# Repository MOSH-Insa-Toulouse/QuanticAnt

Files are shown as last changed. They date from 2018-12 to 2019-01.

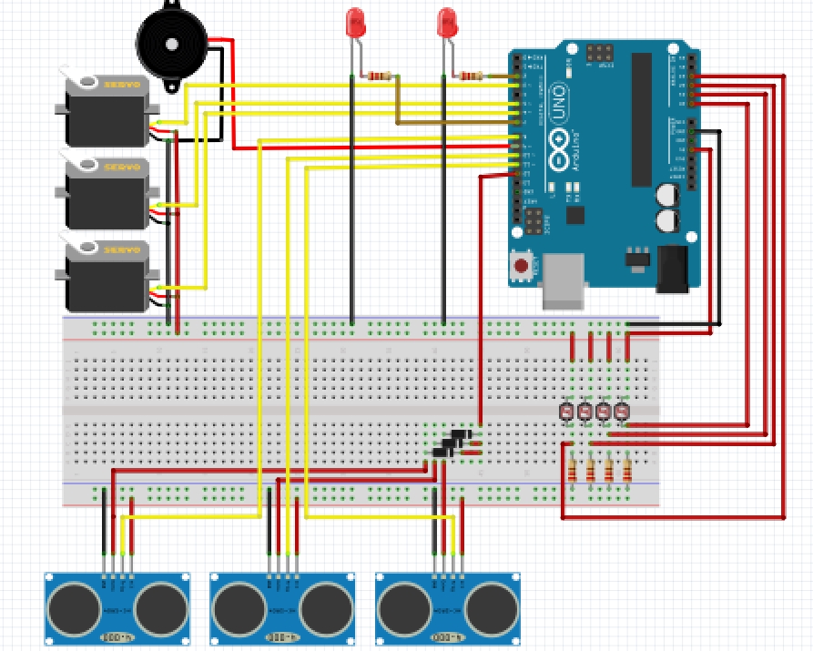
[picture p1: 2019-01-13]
Images et presentation/vueShematique.jpg

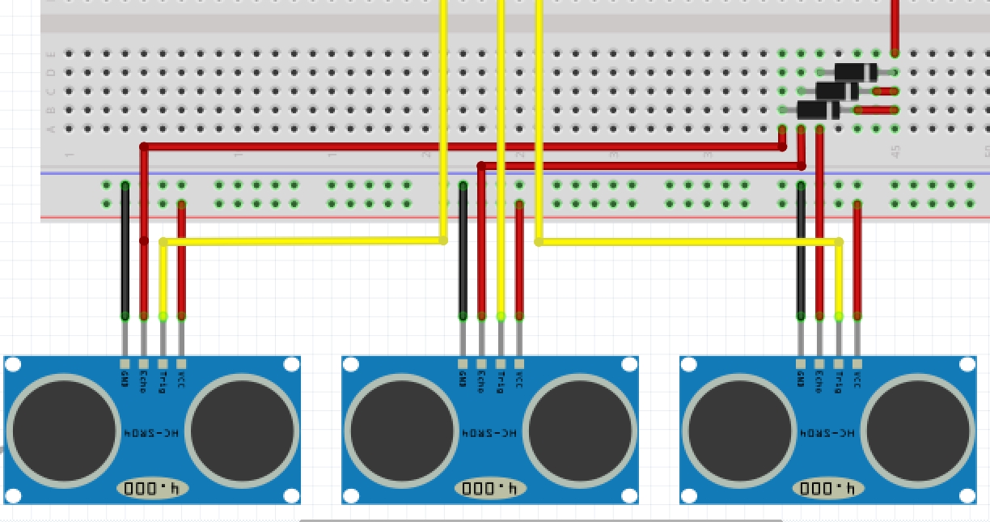
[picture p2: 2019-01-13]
Images et presentation/vueDetailUS.jpg

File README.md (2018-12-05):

# Projet_MOSH 

Auteurs : Quentin Martinez, Nicolas Baudeau, Soufian Yjjou

Caractéristiques de "QuanticAnt" :

Basé sur une arduino, QuanticAnt est un "robot" de petite taille équipé de 4 pattes lui permettant de se déplacer sur le sol.
Les solutions de détections lui permettent d'éviter les obstacles et d'évoluer de façon aléatoire dans une pièce.

QuanticAnt est repoussé par la lumière et emet un son aggaçant quand il se sent bien (peu de lumière ambiante).
Pour prendre le controle de cet insecte l'éclairer directement le force vers une direction donnée.

Mots clés : MARCHE ALEATOIRE, LUMIERE, SANS ROUES, DETECTION D'OBSTACLES

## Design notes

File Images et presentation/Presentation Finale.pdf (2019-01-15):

# Projet MOSH

## Réalisation d’un robot

## “intelligent” : QuanticAnt

BAUDEAU Nicolas - MARTINEZ Quentin - YJJOU Soufian

15/01/2019

# Sommaire

## - Présentation du projet

## - Développement Hardware

## - Développement Software

## - Conclusion

# Présentation du projet

# Objectifs

Idée de départ : Robot imitant le comportement d’un insecte qui a peur de la lumière

Fonctions principales de QuanticAnt :

➔ Éviter les obstacles proches
➔ Gestion de la luminosité (photosensible)
➔ Déplacement aléatoire sur pattes mécaniques
➔ S’immobilise et chante en cas de faible luminosité (mode veille)

# Résultat

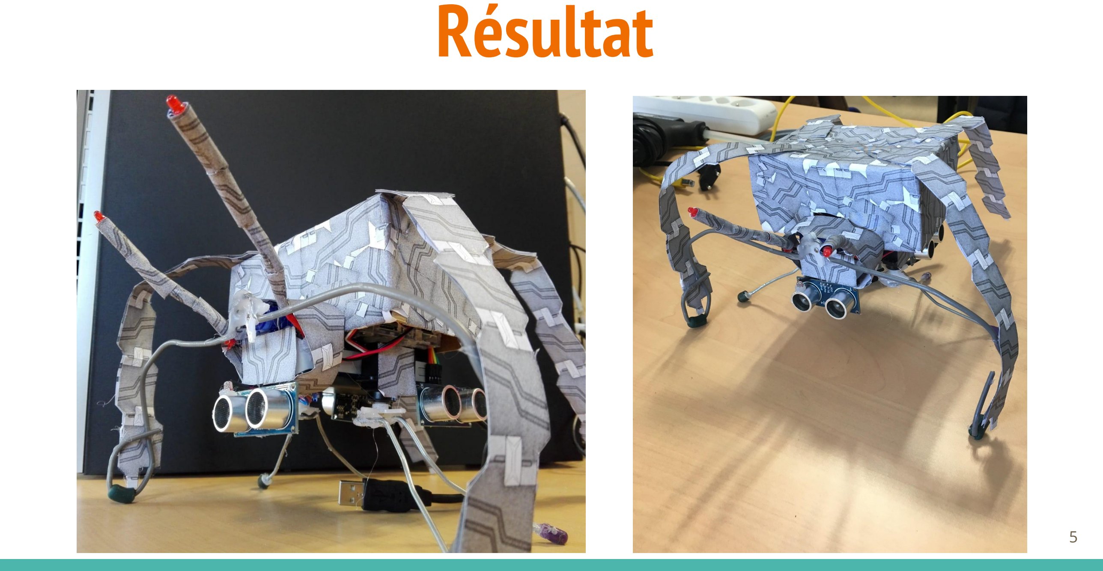
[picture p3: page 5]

# Hardware

# Vue globale de QuanticAnt

Moteurs latéraux | Déphasage pour
permettre le mouvement
Moteur central | Synchronisé pour
permettre le réarmement des pattes latérales
Module ultrason | Détection d’obstacles
Photorésistance | Détection de lumière
Buzzer | Génération du bruit
Led | Antennes clignotantes
Batterie | Alimentation Arduino UNO +
Alimentation moteur

# Composants et prix

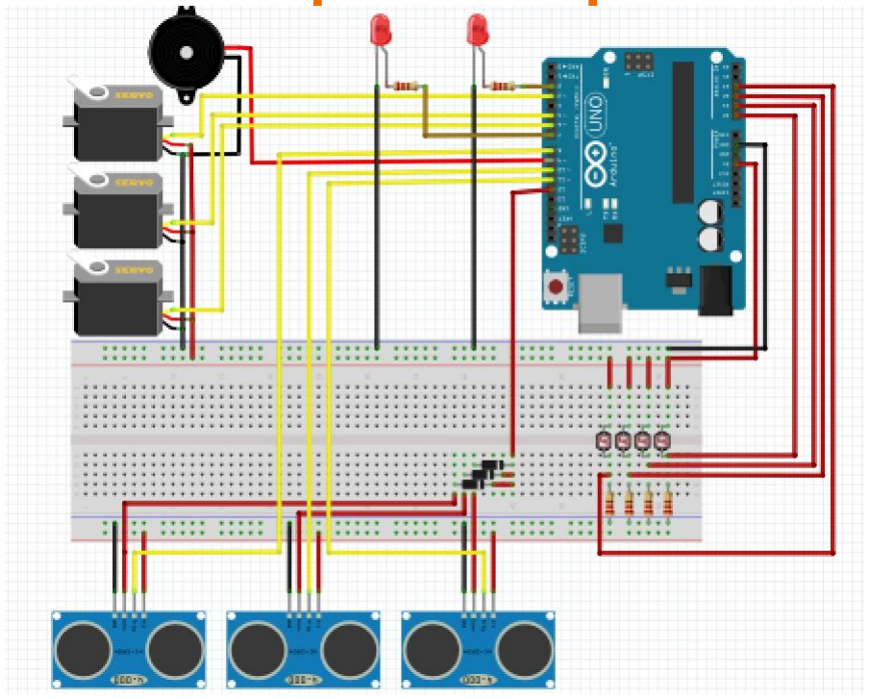
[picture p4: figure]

# Composants et prix

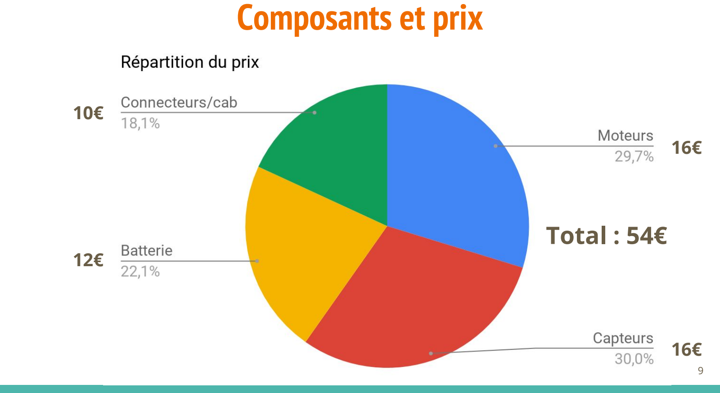
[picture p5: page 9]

## Total : 54€

10€

12€

16€

16€

# Utilisation des modules ultrason

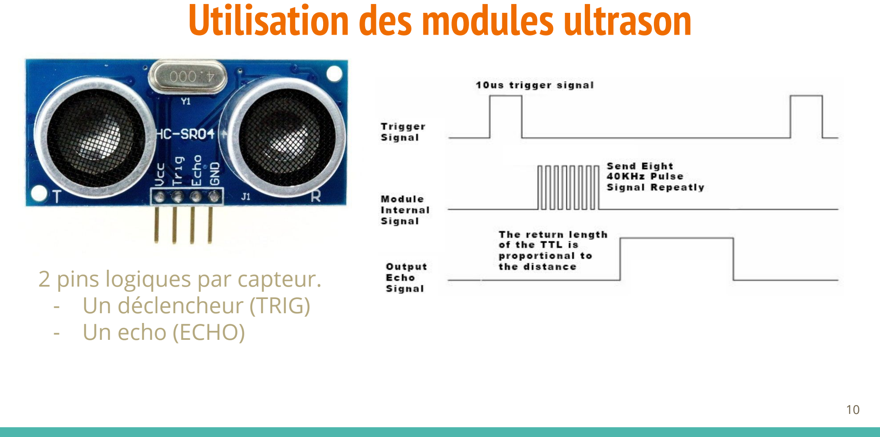
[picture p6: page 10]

2 pins logiques par capteur.
- Un déclencheur (TRIG)
- Un echo (ECHO)

# Utilisation des modules ultrason

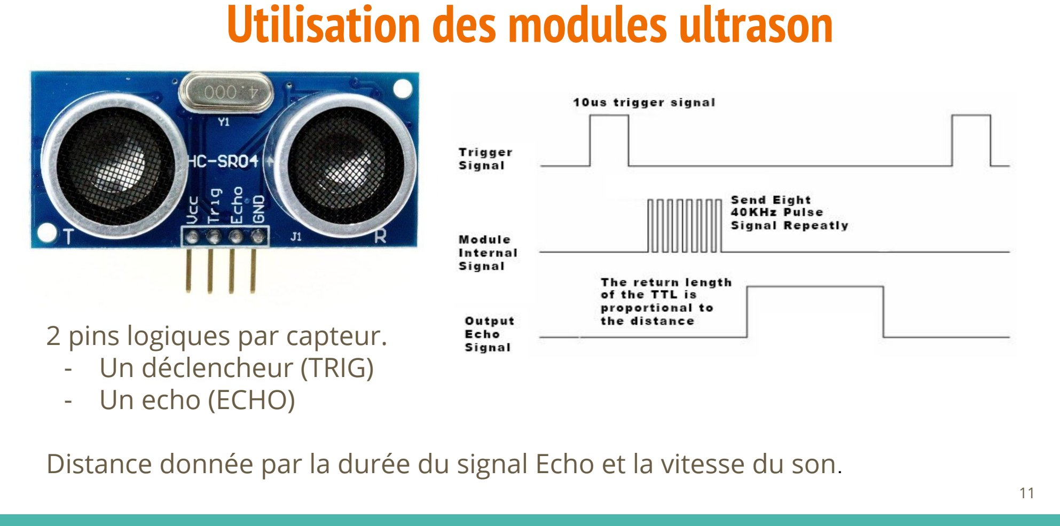
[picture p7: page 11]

2 pins logiques par capteur.
- Un déclencheur (TRIG)
- Un echo (ECHO)

Distance donnée par la durée du signal Echo et la vitesse du son.

# Astuce d’utilisation des modules ultrason

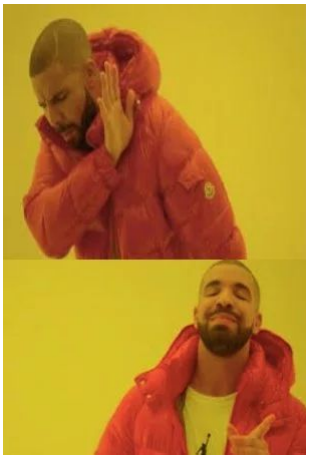
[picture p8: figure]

### 6 pins logiques sur l’arduino…

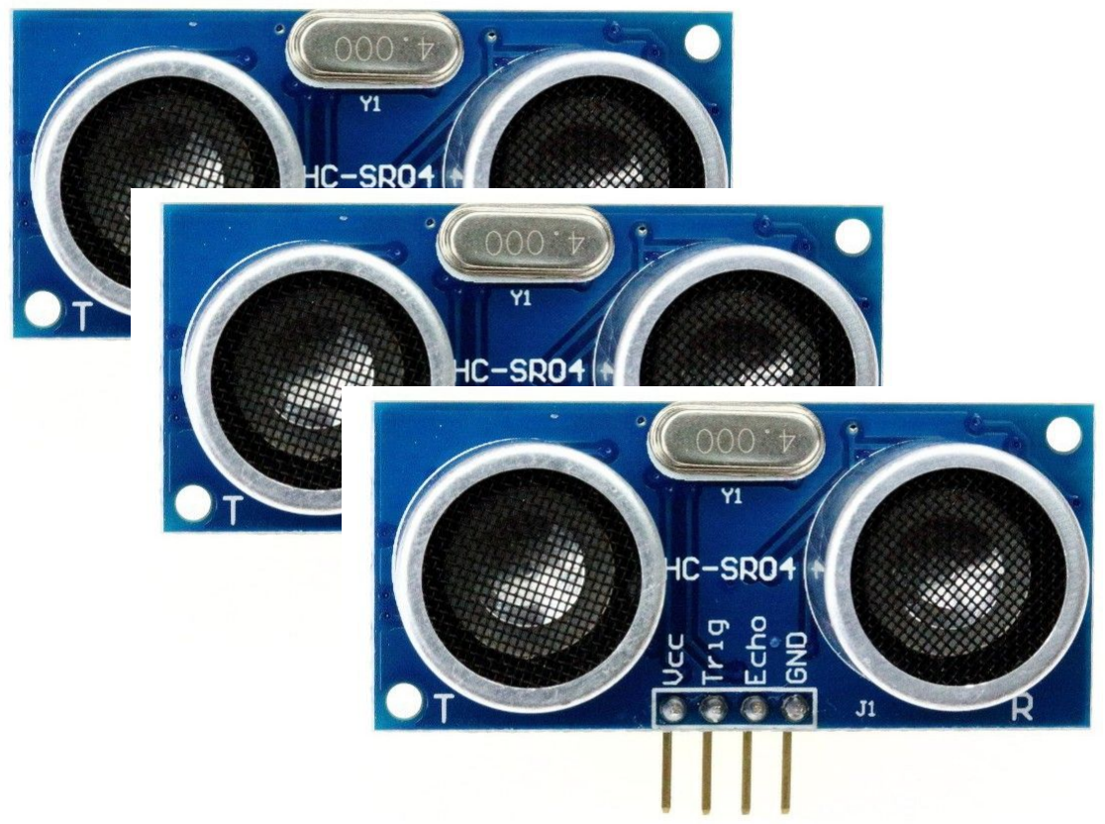
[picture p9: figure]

### 4 pins logiques sur l’arduino…

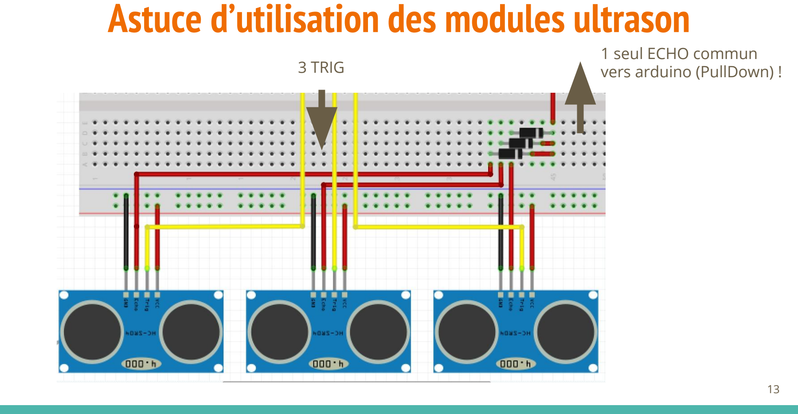
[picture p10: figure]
3 TRIG; 1 seul ECHO commun vers arduino (PullDown) !

# Astuce d’utilisation des modules ultrason

# La conception du PCB (Kicad)

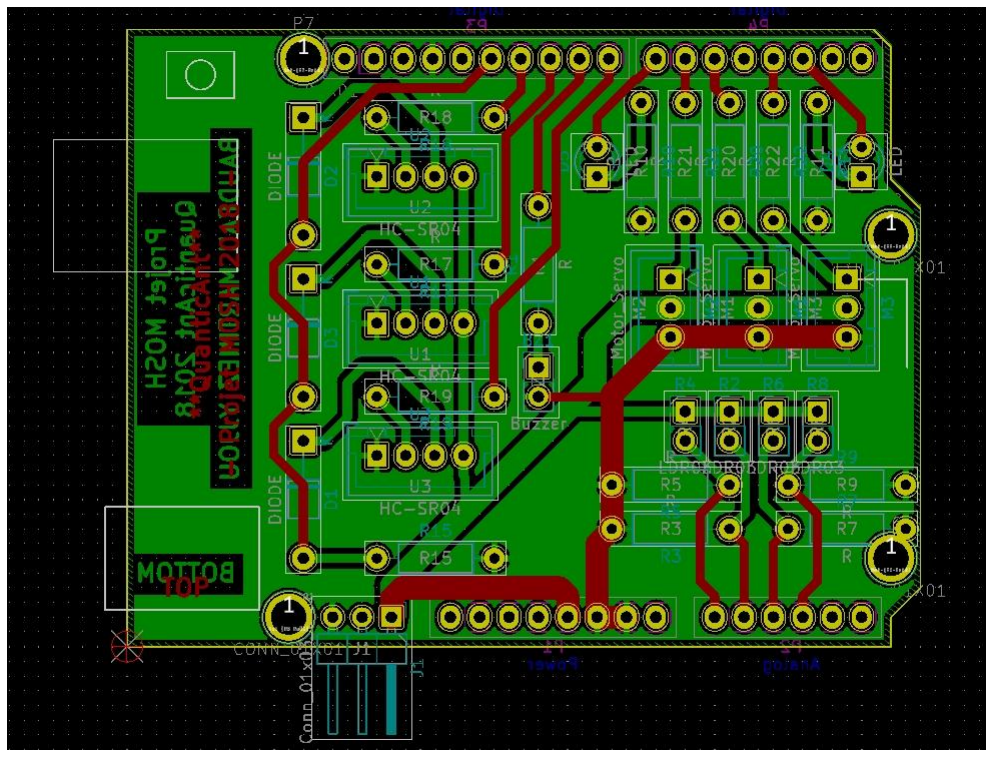
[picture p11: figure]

PCB double face pour :
- Connecter les actionneurs / capteurs
- Contenir les ponts diviseurs des capteurs
- Le système d’Echo commun

# La conception du PCB (Kicad)

PCB double face pour :
- Connecter les actionneurs / capteurs
- Contenir les ponts diviseurs des capteurs
- Le système d’Echo commun

Astuces :
- Indiquer sur les 2 faces “TOP” et “BOTTOM”
- Grossir les pistes des moteurs (puissance)
- Utiliser les pattes des composants comme via

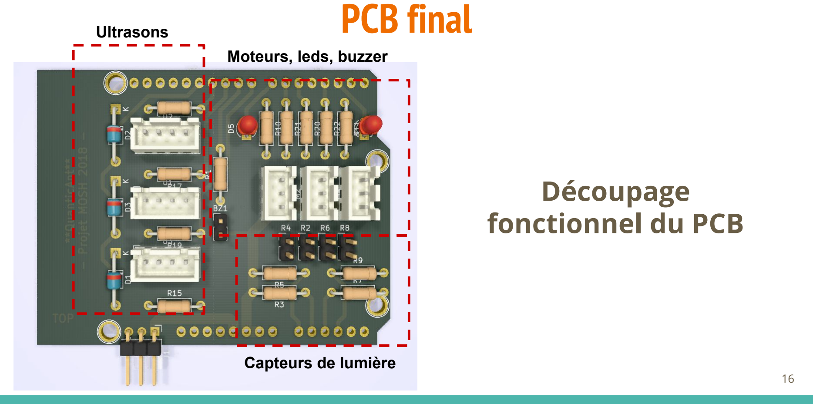
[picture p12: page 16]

Ultrasons | PCB final

Capteurs de lumière

Moteurs, leds, buzzer

## Découpage fonctionnel du PCB

# Software

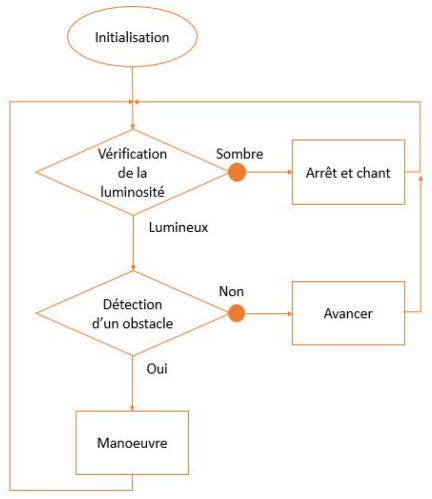
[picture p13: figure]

# Logique de bord

# Logigramme général du robot

# Détection d’un obstacle

➔ Retourne la distance en mm entre le capteur "Broche" et un obstacle à moins de 2m (dure 6ms environ)

➔ Signal = Temps (en ms) entre l’envoie de l'ultrason et ping de réception de l’écho

➔ Conversion du temps en distance 343 m/s soit 0.0343 mm/s = 1/29.1

float DistUS(int Broche)

{
float Dist = 0.0;

//Impulsion pour le capteur ultrason

digitalWrite(Broche, LOW); delayMicroseconds(5);
digitalWrite(Broche, HIGH); delayMicroseconds(10);
digitalWrite(Broche, LOW);

// Lecture du signal détecté par le capteur ultrason.

pinMode(ECHO, INPUT);
Dist = (pulseIn(ECHO, HIGH, 15000)/2) / 29.1;

if(Dist == 0)
return ( 200.0);
else
return (Dist);

# Détection de la luminosité

➔ Retourne la luminosité la plus forte parmi les 4 capteurs

➔ LUXF = Lumière capté devant le robot
➔ LUXR = Lumière capté à droite du robot
➔ LUXG = Lumière capté à gauche du robot
➔ LUXB = Lumière capté derrière le robot

int MaxLux()

{

int maxL = analogReadN(LUXF, 10);

if( analogReadN(LUXL, 10) > maxL) maxL = analogReadN(LUXL, 10);

if( analogReadN(LUXR, 10) > maxL) maxL = analogReadN(LUXR, 10);

if( analogReadN(LUXB, 10) > maxL) maxL = analogReadN(LUXB, 10);

return maxL;

}

# Fonction motrice

➔ On contrôle la (phase) des moteurs en degré (0-180°)

➔ La valeur Dir donne la direction ( 8 = avancer, 4 et 6 = tourner, 2 = reculer)

➔ A = moteur de droite
B = moteur de gauche
C = moteur central

➔ La phase A et B oscillent entre 60° et 130° (pas de 4°)

void Motrice(int vitesse, int dir)

{
if(posA<=59)
sensA =4;
if( posA >= 130)
sensA = -4;

if(posB<=59)
{
sensB =4;

//Contrôle de la phase C au moment où B est en butée

if(dir ==8 || dir == 6)
posC = 70;
else // Dans le cas de la marche avant ou rotation Droite on inverse le mouvement
posC = 110;

# Fonction motrice

➔ La direction désirée est obtenue en corrigeant la position des moteurs A et C en fonction de la position du moteur B

➔ La vitesse est déterminé par le temps d’attente entre deux mouvements

if( posB >= 130)
{
sensB = -4;

//Correction du déphasage avec A selon la direction if(dir ==8 || dir == 2)
posA = 59;
if(dir ==4 || dir == 6)
posA = 130;

//Correction du déphasage avec C selon la direction if(dir == 2 || dir == 4)
posC = 70;
else
posC = 110;
}

posA+=sensA;
posB+=sensB;
phaseA.write(posA);
phaseB.write(posB);
phaseC.write(posC);
delay(80/vitesse);
}

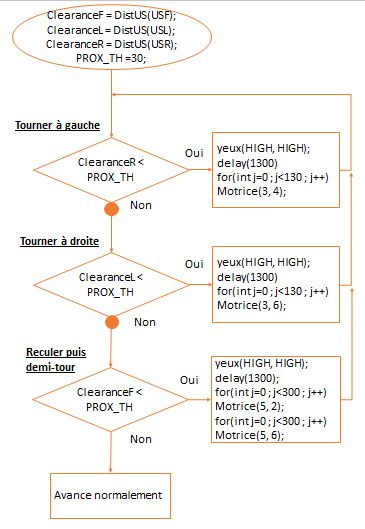
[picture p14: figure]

# Gestion des collisions

# Organigramme de déplacement du robot

# Conclusion

# Difficultés rencontrées

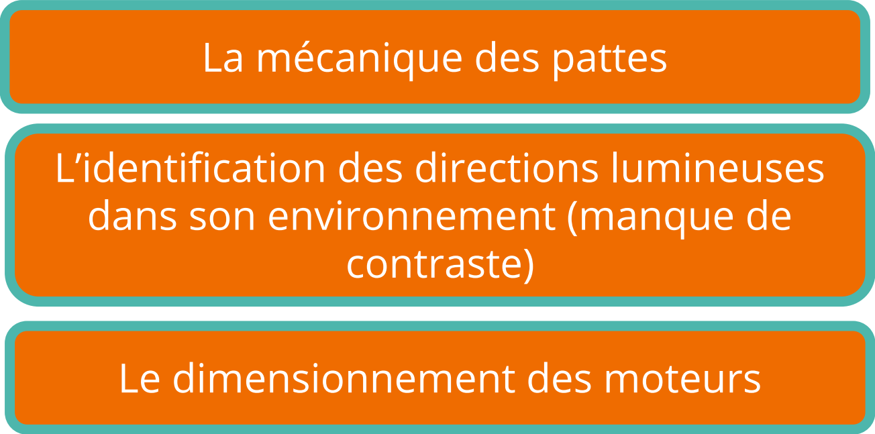
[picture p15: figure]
La mécanique des pattes; dans son environnement (manque de contraste); Le dimensionnement des moteurs

## L’identification des directions lumineuses

# Perspectives d’évolution

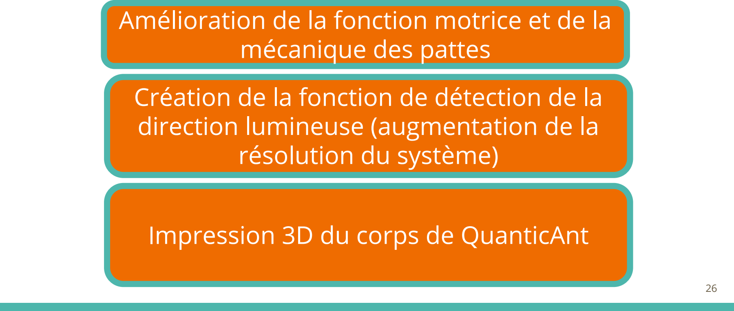
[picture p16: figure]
mécanique des pattes; direction lumineuse (augmentation de la résolution du système); Impression 3D du corps de QuanticAnt

## Amélioration de la fonction motrice et de la

## Création de la fonction de détection de la

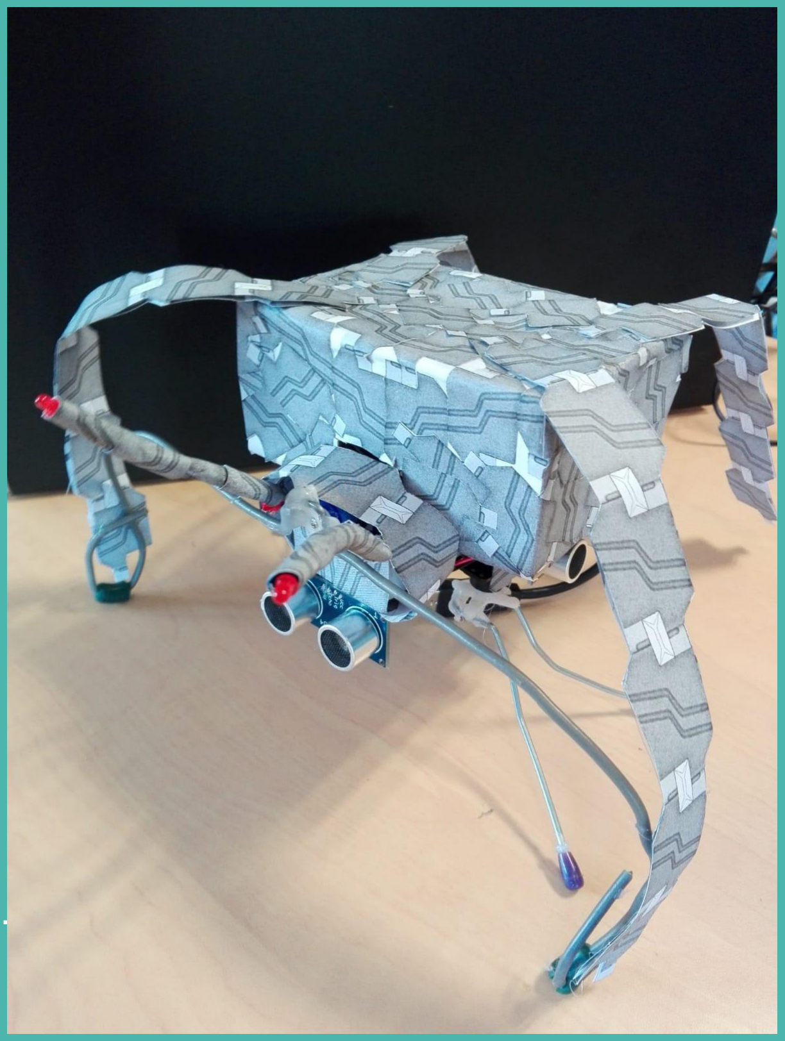
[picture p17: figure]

# Merci de votre attention Démonstration ?

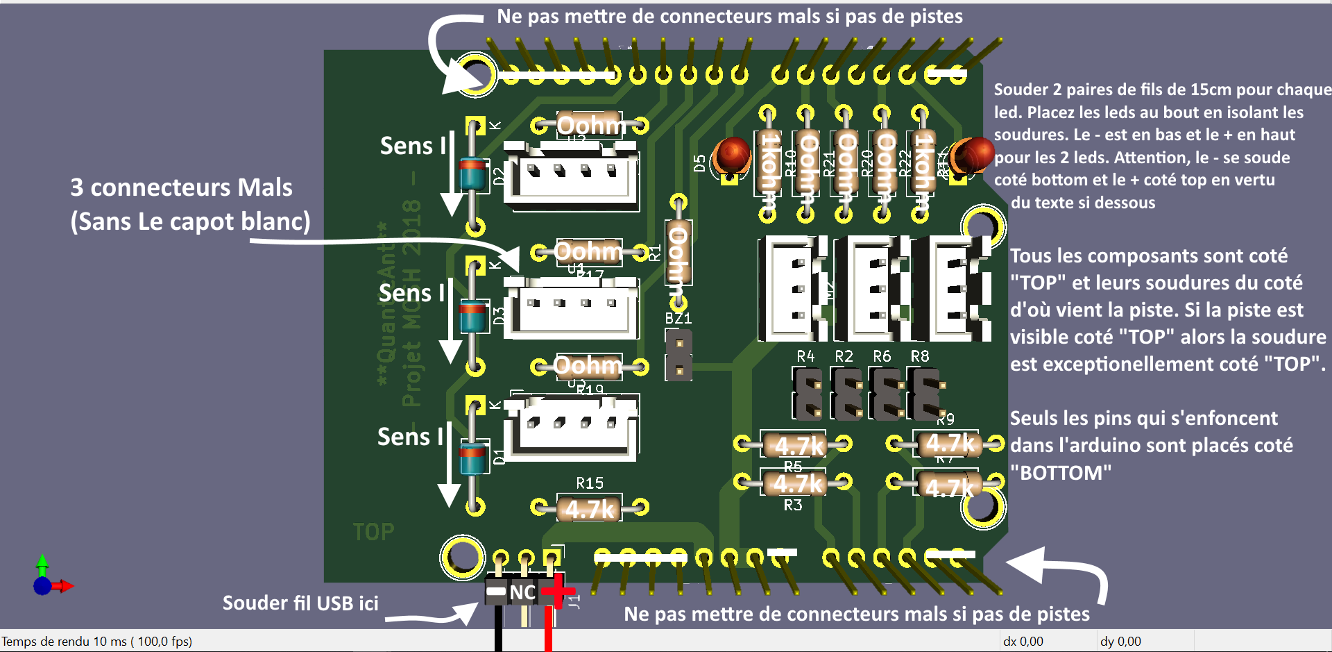
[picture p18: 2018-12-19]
Hardware/PCB/info.png

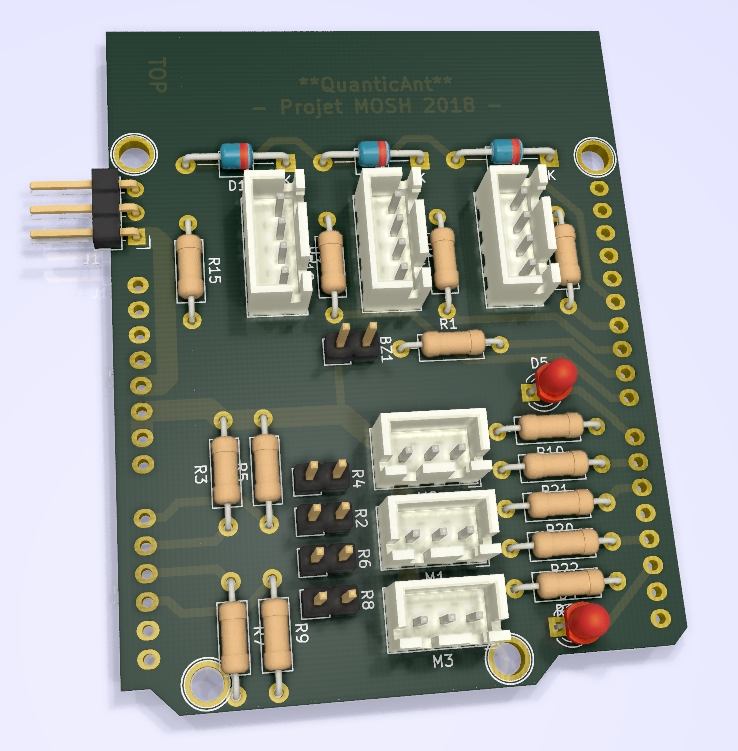
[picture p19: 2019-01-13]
Images et presentation/PCB_3D.jpg

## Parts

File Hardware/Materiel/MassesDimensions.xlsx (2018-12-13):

Projet QuanticAnt
Liste de composants
Designation | Quantité | Longeur(mm) | Largeur (mm) | Profondeur (mm) | masse (g)
Capteurs US | 3 | 45 | 20 | 17 | 7.8
LDR | 4 | 2 | 5 | 5 | 0.2
Arduino Uno + 3Moteurs + Bat + acrylic | 1 | 100 | 80 | 40 | 192
Structure metal Arriere | 1 | 250 | 90 | 50 | 14.7
Structure metal Laterale | 2 | 70 | 80 | 50 | 6.4
Sheild | 1 | 80 | 68 | 20 | 20 | (estimé)
Servo | 1 | 20 | 10 | 30 | 10.9
ON/OFF | 1 | 15 | 18 | 18 | 4.1
Corps 3D printed | 1 |  | 0
led rouge | 2 | 5 | 3 | 3 | 0.1
Buzzer | 1 | 5 | 22 | 22 | 2.3
1n4148 | 3 |  |  |  | 0.1

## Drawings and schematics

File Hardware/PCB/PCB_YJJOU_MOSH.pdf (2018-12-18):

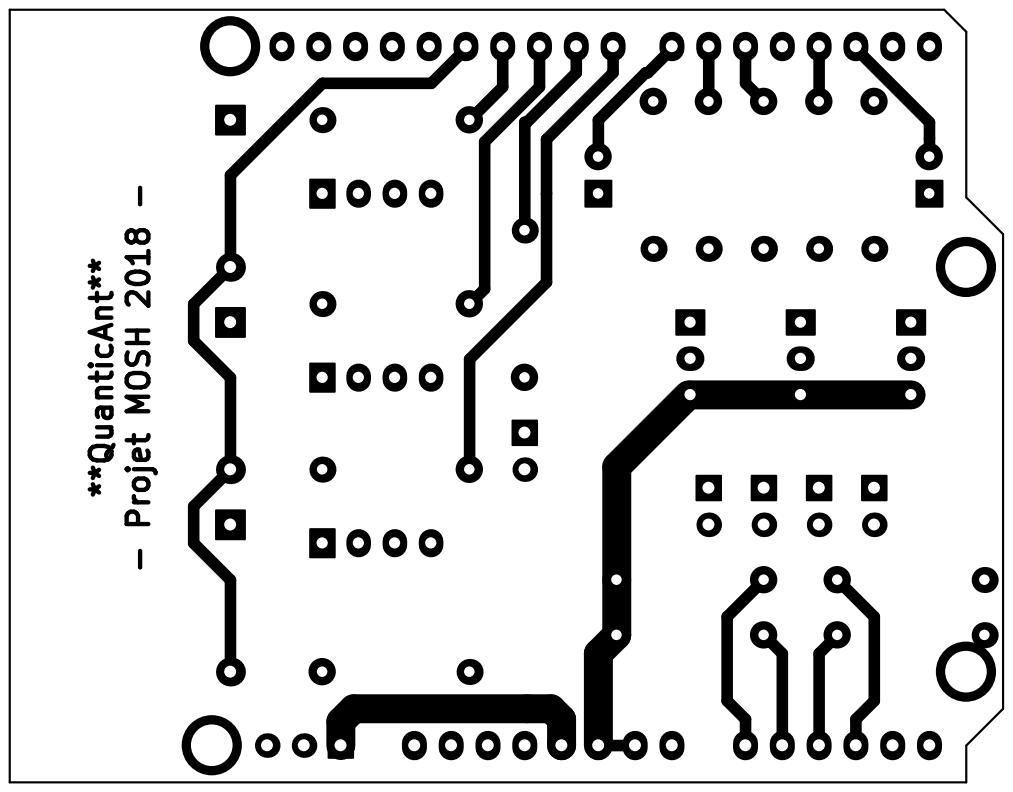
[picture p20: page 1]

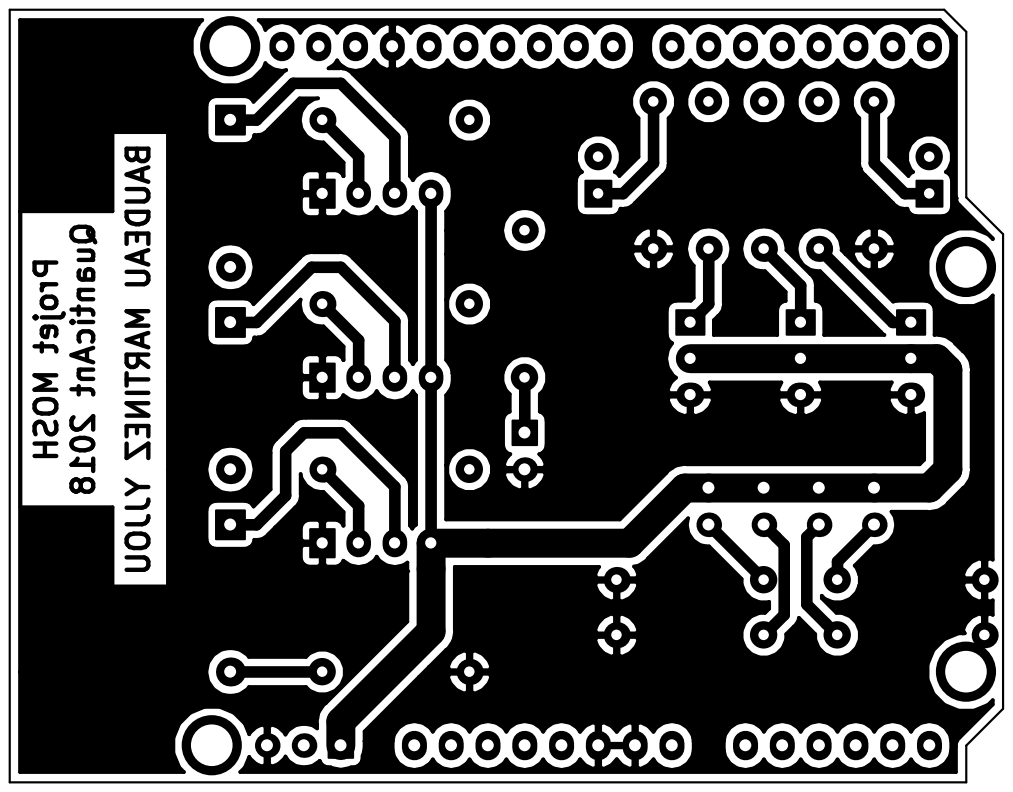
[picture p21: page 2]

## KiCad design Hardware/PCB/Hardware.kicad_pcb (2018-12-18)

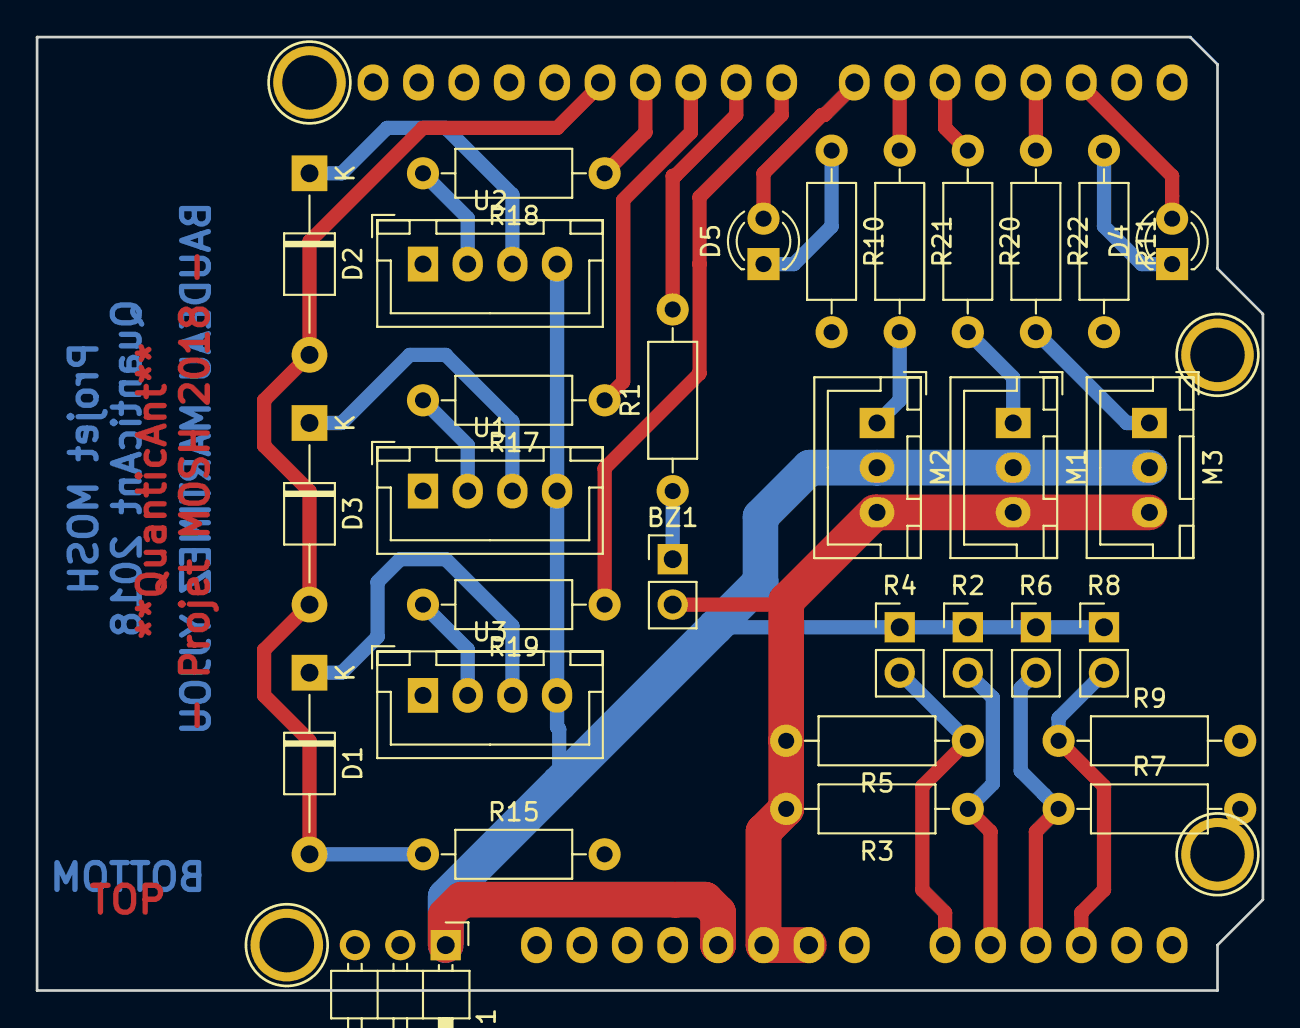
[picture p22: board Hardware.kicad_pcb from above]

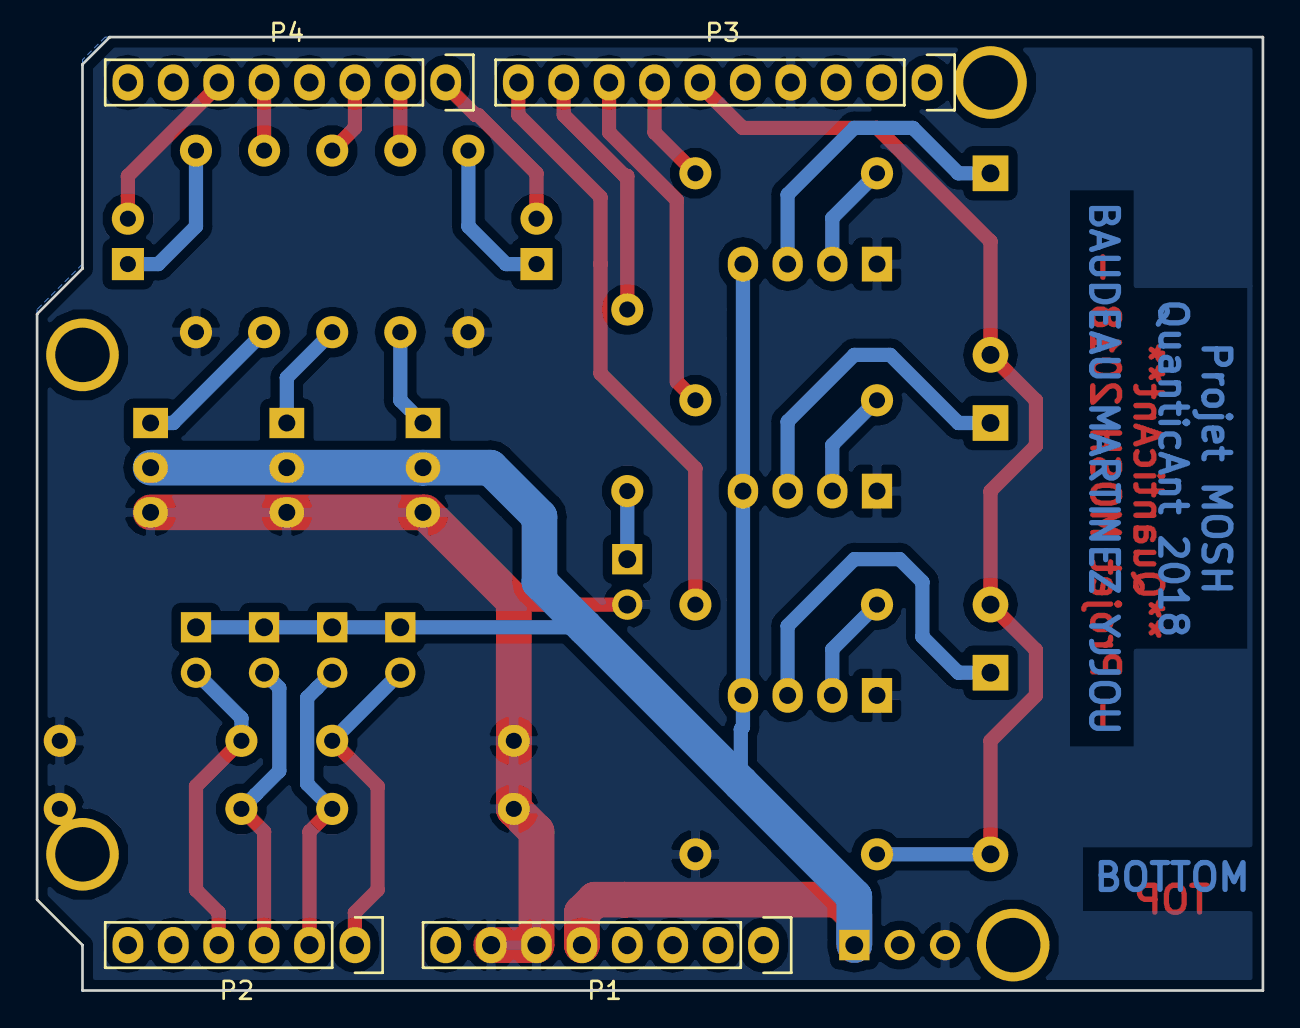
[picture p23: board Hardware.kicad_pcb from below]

Board: 2 copper layers, 68.6 x 53.3 mm, 39 parts (4 on the bottom side), 28 nets.

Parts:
BZ1: Buzzer; PinHeader_1x02_P2.54mm_Vertical
D1, D2, D3: DIODE; D_T-1_P10.16mm_Horizontal
D4, D5: LED; LED_D3.0mm
J1: Conn_01x03_Male; PinHeader_1x03_P2.54mm_Horizontal
M1, M2, M3: Motor_Servo; JST_XH_B03B-XH-A_1x03_P2.50mm_Vertical
P1: Power; Socket_Strip_Arduino_1x08
P2: Analog; Socket_Strip_Arduino_1x06
P3: Digital; Socket_Strip_Arduino_1x10
P4: Digital; Socket_Strip_Arduino_1x08
P5, P6, P7, P8: CONN_01X01; Arduino_1pin
R1, R3, R5, R7, R9, R10, R11, R15, R17, R18, R19, R20, R21, R22: R; R_Axial_DIN0207_L6.3mm_D2.5mm_P10.16mm_Horizontal
R2, R4, R6, R8: LDR03; PinHeader_1x02_P2.54mm_Vertical
U1, U2, U3: HC-SR04; JST_XH_B04B-XH-A_1x04_P2.50mm_Vertical

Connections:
+5V: J1.1, M1.2, M2.2, M3.2, P1.5, R2.1, R4.1, R6.1, R8.1, U1.4, U2.4, U3.4
/2: D4.2, P4.6
/3(**): P4.5, R22.1
/5(**): P4.3, R20.1
/6(**): P4.2, R21.1
/7: D5.2, P4.1
/8: P3.10, R19.1
/9(**): P3.9, R1.2
/10(**/SS): P3.8, R17.1
/11(**/MOSI): P3.7, R18.1
/12(MISO): D1.2, D2.2, D3.2, P3.6, R15.1
/A0: P2.1, R4.2, R5.1
/A1: P2.2, R2.2, R3.1
/A2: P2.3, R6.2, R7.1
/A3: P2.4, R8.2, R9.1
GND: BZ1.2, J1.3, M1.3, M2.3, M3.3, P1.6, P1.7, P3.4, R3.2, R5.2, R7.2, R9.2, R10.2, R11.2, R15.2, U1.1, U2.1, U3.1
unnamed: BZ1.1, R1.1
unnamed: D1.1, U3.3
unnamed: D2.1, U2.3
unnamed: D3.1, U1.3
unnamed: D4.1, R11.1
unnamed: D5.1, R10.1
unnamed: M1.1, R20.2
unnamed: M2.1, R21.2
unnamed: M3.1, R22.2
unnamed: R17.2, U1.2
unnamed: R18.2, U2.2
unnamed: R19.2, U3.2

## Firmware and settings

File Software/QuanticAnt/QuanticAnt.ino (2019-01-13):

/***********************************************************************
* 
*.______   .______        ______          __   _______ .___________.   .___  ___.   ______        _______. __    __  
*|   _  \  |   _  \      /  __  \        |  | |   ____||           |   |   \/   |  /  __  \      /       ||  |  |  | 
*|  |_)  | |  |_)  |    |  |  |  |       |  | |  |__   `---|  |----`   |  \  /  | |  |  |  |    |   (----`|  |__|  | 
*|   ___/  |      /     |  |  |  | .--.  |  | |   __|      |  |        |  |\/|  | |  |  |  |     \   \    |   __   | 
*|  |      |  |\  \----.|  `--'  | |  `--'  | |  |____     |  |        |  |  |  | |  `--'  | .----)   |   |  |  |  | 
*| _|      | _| `._____| \______/   \______/  |_______|    |__|        |__|  |__|  \______/  |_______/    |__|  |__| 
*                                                                                                                    
* ___     ___    __    ___         ___     ___    __    ___                                                          
*|__ \   / _ \  /_ |  / _ \       |__ \   / _ \  /_ |  / _ \                                                         
*   ) | | | | |  | | | (_) |  ______ ) | | | | |  | | | (_) |                                                        
*  / /  | | | |  | |  > _ <  |______/ /  | | | |  | |  \__, |                                                        
* / /_  | |_| |  | | | (_) |       / /_  | |_| |  | |    / /                                                         
*|____|  \___/   |_|  \___/       |____|  \___/   |_|   /_/                                                          
*                                                                                                                    
*  ______      __    __       ___      .__   __. .___________. __    ______         ___      .__   __. .___________. 
* /  __  \    |  |  |  |     /   \     |  \ |  | |           ||  |  /      |       /   \     |  \ |  | |           | 
*|  |  |  |   |  |  |  |    /  ^  \    |   \|  | `---|  |----`|  | |  ,----'      /  ^  \    |   \|  | `---|  |----` 
*|  |  |  |   |  |  |  |   /  /_\  \   |  . `  |     |  |     |  | |  |          /  /_\  \   |  . `  |     |  |      
*|  `--'  '--.|  `--'  |  /  _____  \  |  |\   |     |  |     |  | |  `----.    /  _____  \  |  |\   |     |  |      
* \_____\_____\\______/  /__/     \__\ |__| \__|     |__|     |__|  \______|   /__/     \__\ |__| \__|     |__|      
*                                                                                                                    
* de l'équipe Nicolas, Quentin et Soufian
*  
* Le projet vise à réaliser un robot imitant le comportement d'un insecte.
* -Déplacements aléatoires sur pattes
* -Photosensible
* -Evitement d'obstacles proches
* -s'immobilise et "Chante" lorsque la luminosité est faible
* 
* 
* 
***********************************************************************/

#include <Servo.h> // Voir l'exemple "SERVO" dans le menu arduino

#define USL 11 //Ultrason Left
#define USF 8//Ultrason Front
#define USR 10//Ultrason Right
#define ECHO 12//Retour ultrason
#define BUZZ 9//Buzzer pin (doit etre PWM)
#define LUXL A0//Lumiere Front (doit etre analog)
#define LUXB A1//Lumiere Back (doit etre analog)
#define LUXR A2//Lumiere Left (doit etre analog)
#define LUXF A3//Lumiere Right (doit etre analog)
#define LEDR 2 // led droite rouge
#define LEDL 7 // led gauche rouge

#define PROX_TH 30 // distance en cm a partir de laquelle le robot veut changer de direction
#define NIGHTLEV 400 // Niveau de lumiere correspondant a la nuit (plus grande la valeur, plus facilement le robot passe en mode nuit)
//Variables globales
int C=0; //compteur de loop avec overflow
int quantic=0; // Valeur aleatoire entre 0 et 100 qui change a chaque boucle
int ClearanceF = 100; //distances ultrason mesurees front (defaut 1m)
int ClearanceR = 100;
int ClearanceL = 100;

//----Variables Motrices
//Sens de rotations et positions initiales
int sensA =1;
int sensB =-1;
int sensC =1;
int posA = 59;
int posB = 139;
int posC = 65;
Servo phaseA;  // Moteur droite pin 3
Servo phaseB;  // Moteur gauche pin 5
Servo phaseC;  // Moteur equilibrage pin 6








//Retourne la moyenne de N mesures (moins de bruit) Attention, ne pas utiliser sur un pont diviseur fragile. (>10kohm)
long analogReadN(int pin, int N)
{
  long moy = 0;
  for(int i=0; i<N ; i++)
    moy += analogRead(pin);
    
  return(moy/N);
}



// Fonction qui genere un bruit une fois invoquee. Inspiree de l'exemple "tone"
// Fonction bloquante, attention ! (le temps du bruit)
void bruit() {
    
    int melody[] =        {208, 494, 415, 494, 415}; //tons du buzzer
    int noteDurations[] = {96, 96, 96, 96, 96}; // Durees des tons
  
    for (int thisNote = 0; thisNote < 5; thisNote++)
    {
      int noteDuration = 3000 / noteDurations[thisNote];
      int pauseBetweenNotes = noteDuration * 1.30;
      tone(BUZZ, melody[thisNote], noteDuration);
      delay(pauseBetweenNotes);
      // stop the tone playing:
      noTone(BUZZ);
    }
}


//Fonction qui retourne la distance en mm entre le capteur "Broche" et un obstacle à moins de 2m.
//Bloque le code pendant 6ms max
float DistUS(int Broche) {
  float Dist = 0.0;
  //Impulsion pour le capteur US
  digitalWrite(Broche, LOW);
  delayMicroseconds(5);
  digitalWrite(Broche, HIGH);
  delayMicroseconds(10);
  digitalWrite(Broche, LOW);
 
  // Recupere le signal echo des capteurs
  // La duree est en microseconds
  pinMode(ECHO, INPUT);
  Dist = (pulseIn(ECHO, HIGH, 15000)/2) / 29.1;
  // conversion du temps en distance en divisant par 29.1
  if(Dist == 0)
   return ( 200.0);
  else
   return (Dist);   

}


// Retourne La direction sombre
int DirLowLux() {
  //Front, Right, Back, Left 0° -> 360° sens horaire
  int LumF =  analogReadN(LUXF, 10);
  int LumL =  analogReadN(LUXL, 10);
  int LumR =  analogReadN(LUXR, 10);
  int LumB =  analogReadN(LUXB, 10);

  if(LumF > LumR && LumF > LumL && LumF > LumB)
   return(2); // Derriere
  if(LumR > LumF && LumR > LumL && LumR > LumB)
   return(4); // gauche
 if(LumB > LumR && LumB > LumL && LumB > LumF)
   return(8); // Devant
 if(LumL > LumR && LumL > LumF && LumL > LumB)
   return(6); // Droite
}

//Retourne la luminosite la plus forte (sonde les 4 capteurs).
int MaxLux() {
  int maxL = analogReadN(LUXF, 10);
  if( analogReadN(LUXL, 10) > maxL)
     maxL = analogReadN(LUXL, 10);
  if( analogReadN(LUXR, 10) > maxL)
     maxL = analogReadN(LUXR, 10);
  if( analogReadN(LUXB, 10) > maxL)
     maxL = analogReadN(LUXB, 10);
  return maxL;
}


//Controle des yeux rouge du robot
void yeux(int droite, int gauche)
{
  digitalWrite(LEDR, droite);
  digitalWrite(LEDL, gauche);
}




// Deplace QuanticAnt a la vitesse speed. La valeur Dir donne la direction selon le pave numerique
//789 : 8 = avancer
//456 : 4 et 6 = tourner
//123 : 2 = reculer
void Motrice(int vitesse, int dir)
{

  //La phase A oscille entre 60 et 130
  if(posA<=59)
      sensA =4;
  if( posA >= 130)
      sensA = -4;

  // La phase B oscille entre 60 et 130
  if(posB<=59)
  {
      sensB =4;
      //Controle de la phase C au moment ou B est en butee
      if(dir ==8 || dir == 4)
        posC = 70;
      else // Dans le cas de la marche avant ou rotation Droite on inverse le mouvement
        posC = 110;
  }
    if( posB >= 130)
    {
      sensB = -4;

      //Correction du dephasage avec A selon la direction
      if(dir ==8 || dir == 2)
        posA = 59;
      if(dir ==4 || dir == 6)
        posA = 130;

      //Correction du dephasage avec C selon la direction  
      if(dir == 2 || dir == 6)
        posC = 70;
      else
        posC = 110;


    }
    
    posA+=sensA;
    posB+=sensB;
    phaseA.write(posA);           
    phaseB.write(posB);         
    phaseC.write(posC);        
    delay(80/vitesse);  
}





// Execution unique
void setup() {
  
  //Initialisation des capteurs US
  pinMode(LUXF, INPUT);
  pinMode(LUXB, INPUT);
  pinMode(LUXR, INPUT);
  pinMode(LUXL, INPUT);
  pinMode(USL, OUTPUT);
  pinMode(USF, OUTPUT);
  pinMode(USR, OUTPUT);
  pinMode(ECHO, OUTPUT);
  digitalWrite(USL, LOW);
  digitalWrite(USF, LOW);
  digitalWrite(USR, LOW);
  

  randomSeed(analogRead(A4)); // Recuperation des parasites pour generer le random
  
  //Preparation des moteurs
  phaseA.attach(3);
  phaseB.attach(5); 
  phaseC.attach(6);
  
  phaseA.write(posA);              
  phaseB.write(posB);        
  phaseC.write(posC);   

  
  Serial.begin(9600);


  //Le robot dit bonjour
  for(int j=0; j<5 ;j++)
  {
    bruit();
    yeux(HIGH, LOW);
    delay(50);
    yeux(LOW, HIGH);
    delay(50);
  }
  yeux(LOW, LOW);
}


/*Logique de bord :
1) Verifier la luminosité. Sombre => arret et chant
2) sinon verifier la position des obstacles => manoeuvre
3) sinon aller vers l'avant

Evolution possible : Utiliser les 4 capteurs de luminosite pour diriger le robot vers le noir.
Les capteurs sont presents mais pas utilises dans le code actuel. La fonction qui determine la direction sombre
est deja codee.
*/


void loop() {


  
  quantic = random(0, 100); // Nombre aleatoire de ce cycle

  //Recuperation des distances aux objets (prend du temps !!)
  ClearanceF = DistUS(USF);
  ClearanceL = DistUS(USL);
  ClearanceR = DistUS(USR);

  Serial.println("Avant "+String(ClearanceF));
  Serial.println("Gauche "+String(ClearanceL));
  Serial.println("Droite "+String(ClearanceR));
  Serial.println("--------");

  //Comportement dans le noir
  if(MaxLux() < NIGHTLEV)
  {
    //Comportement aleatoire des yeux
    if(quantic < 10)
      yeux(LOW, LOW);
    if(quantic >= 10 && quantic < 40)
      yeux(LOW, HIGH);
    if(quantic >= 40 && quantic < 80)
      yeux(HIGH, LOW);
    if(quantic >= 80)
      yeux(HIGH, HIGH);
      
    phaseC.write(90); // relaxe le moteur avant 
    delay(100);
    if(C%7 == 0)
      bruit(); //Blocant quelques diziemes de secondes
      
  }
  else // Il fait jour, on se deplace
  {
    yeux(LOW, LOW);
 
    //Gestion des collisions.
    if((ClearanceR < PROX_TH)) // Tourner vers gauche
    {
       yeux(HIGH, HIGH);
       delay(1300); // Le robot fait le mort
       for(int j=0 ; j<130 ; j++) 
        Motrice(3, 4);
    }
    else if( ClearanceL < PROX_TH)// Tourner vers droite
    {
       yeux(HIGH, HIGH);
       delay(1300); // Le robot fait le mort
       for(int j=0 ; j<130 ; j++) 
        Motrice(3, 6);
    }
    else if(ClearanceF < PROX_TH)// Reculer puis demi-tour
    {
     yeux(HIGH, HIGH);
     delay(1300); // Le robot fait le mort
    for(int j=0 ; j<300 ; j++) 
      Motrice(5, 2);
    for(int j=0 ; j<300 ; j++) 
      Motrice(5, 4);

    }
    if(ClearanceL>PROX_TH && ClearanceR>PROX_TH && ClearanceF>PROX_TH) // Aucun objet ne gene. On execute la marche habituelle du robot
    {

      //Fonction de marche aleatoire 1% dns un sens, 3% dans l'autre, 96% tout droit 
//    if(quantic < 2) // Parfois l'insecte tourne sans raison dans un sens
//    {
//     for(int j=0 ; j<30 ; j++) 
//        Motrice(3, 4);
//    }
//    if(quantic >= 2 && quantic < 5) // ou dans l'autre !
//    {
//     for(int j=0 ; j<30 ; j++) 
//        Motrice(3, 6);
//    }
//    if(quantic >= 5) // Le reste du temps il avance
//    {
//    for(int j=0 ; j<30 ; j++)   
//      Motrice(3, 8);
//    }
//    Serial.println(quantic);
//    Motrice(8, DirLowLux()); // Suivi de direction sombre desactive. (instable, besoin de lissage).
//    Serial.println("LowLUX "+String(DirLowLux()));
      for(int j=0 ; j<40 ; j++)   
      Motrice(3, 8);

    
   }

  }
  

  C++; // Compteur de boucle
}

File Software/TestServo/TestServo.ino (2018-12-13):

/* Sweep
 by BARRAGAN <http://barraganstudio.com>
 This example code is in the public domain.

 modified 8 Nov 2013
 by Scott Fitzgerald
 http://www.arduino.cc/en/Tutorial/Sweep
*/

#include <Servo.h>

//Sens de rotations et positions initiales
int sensA =1;
int sensB =-1;
int sensC =1;
int posA = 59;
int posB = 139;
int posC = 65;
Servo phaseA;  // Moteur droite
Servo phaseB;  // Moteur gauche
Servo phaseC;  // Moteur equilibrage


void setup() {
  phaseA.attach(9);  // attaches the servo on pin 9 to the servo object
  phaseB.attach(10);  // attaches the servo on pin 9 to the servo object
  phaseC.attach(11);  // attaches the servo on pin 9 to the servo object
  Serial.begin(9600);
     phaseA.write(posA);              // tell servo to go to position in variable 'pos'
    phaseB.write(posB);              // tell servo to go to position in variable 'pos'
    phaseC.write(posC);   
  delay(500);

  pinMode(3, INPUT);
  
}

// vitesse de 1 a 5
// dir valeurs acceptees 2, 4, 6, 8.(pave num)
void motrice(int vitesse, int dir)
{
  if(posA<=59)
      sensA =4;
  if( posA >= 130)
      sensA = -4;

    if(posB<=59)
    {
      sensB =4;
      if(dir ==2 || dir == 6)
        posC = 70;
      else
        posC = 110;
    }
    if( posB >= 130)
    {
      if(dir ==2 || dir == 8)
        posA = 59;
     if(dir ==4 || dir == 8)
        posA = 130;
      sensB = -4;
      if(dir == 8 || dir == 4)
        posC = 70;
      else
        posC = 110;
    }
    
    posA+=sensA;
    posB+=sensB; 
    phaseA.write(posA);              // tell servo to go to position in variable 'pos'
    phaseB.write(posB);              // tell servo to go to position in variable 'pos'
    phaseC.write(posC);              // tell servo to go to position in variable 'pos'
    delay(80/vitesse);  
}

void loop() {
    // in steps of 1 degree

    
  
  
}

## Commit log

2018-12-05 Deplacement du projet depuis git perso vers git du cours.
    [Hardware.kicad_pcb, Hardware.sch, Liste.xlsx]
2018-12-06 Liste des taches
    [Taches a effectuer.xlsx]
2018-12-08 Commentaire répartition taches dans code arduino
    [Taches a effectuer.xlsx]
2018-12-08 Ajout de SERVO.h. Corrections de fonction LUX
    [QuanticAnt.ino]
2018-12-10 Inversion roles quentin/souf dans le code
    [Taches a effectuer.xlsx]
2018-12-13 Ajout de liste des dimensions - MAJ des taches
    [MassesDimensions.xlsx, Taches a effectuer.xlsx]
2018-12-14 Nouveau PCB simplifié
    [Hardware.kicad_pcb, Hardware.sch]
2018-12-14 PCB corrigé et verifié. Typon prêt
    [Hardware.kicad_pcb, Hardware.sch, Taches a effectuer.xlsx]
2018-12-15 Code testeur UltraSon+Diodes sur PCB Ajout pull down sur la ligne ECHO
    [Hardware.kicad_pcb, Hardware.sch]
2018-12-15 Texte sur le pcb pour eviter erreur de gravure
    [Hardware.kicad_pcb, Hardware.sch]
2018-12-16 Update QuanticAnt.ino
    Correction des pins attribués. Ajout de la fonction bruit
    [QuanticAnt.ino]
2018-12-16 Update QuanticAnt.ino
    Ajout de la fonction motrice et des commandes Leds des yeux.
2018-12-17 Modification epaisseur pistes 0,4mm => 0,8mm (il reste des pistes a grossir)
    [Hardware.kicad_pcb]
2018-12-17 Premieres modifs apres commentaire de cathy
    [Hardware.kicad_pcb]
2018-12-18 PCB final
    [Hardware.kicad_pcb, Hardware.sch, Taches a effectuer.xlsx]
2018-12-19 Correction comportement erratique moteurs + Fonction US et LUX pris en compte + Tests en environnement hostile
    [Taches a effectuer.xlsx]
2018-12-19 Quelques commentaires dans le code arduino
2019-01-05 Erreur de pin pour le buzzer corrigee.
    [QuanticAnt.ino]
2019-01-08 Corrections du comportement face aux obstacles Correction du bruit d'obscurite
    [QuanticAnt.ino]
2019-01-10 Modif cosmetiques du code. Ajout d'un aleatoire dans la marche 5% tourne droite 5% gauche 90 % devant. Ajout d'un hello world du robot au statup. Ajout d'un meilleur effet random des yeux dans le noi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
2019-01-10 Niveau de nuit en #define plutot que hardcode
2019-01-10 Mise a jour des taches effectuees
    [Taches a effectuer.xlsx]
2019-01-11 Correction mouvement lent retrait fonction aleatoire
    [QuanticAnt.ino]
2019-01-11 Dessin shematique
    [RepresentationShema.fzz]
2019-01-13 Correction commentaires code. Ajout images du PCB et du Fritzing. Un peu d'ascii art
    [RepresentationShema.fzz]
2019-01-13 Retrait du document faisant doublon avec le devis.
    [Liste.xlsx]
2019-01-13 Update QuanticAnt.ino
    Correction de commentaires
    [QuanticAnt.ino]
2019-01-13 Delete 4065fb.pdf
    Document non utilisé pour cette version de QuanticAnt (utilisation du powerbank)
